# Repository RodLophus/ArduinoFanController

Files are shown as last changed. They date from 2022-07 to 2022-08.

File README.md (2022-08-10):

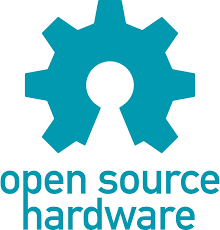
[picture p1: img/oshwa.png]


# ArduinoFanController

Controls and monitors up to 4 PC-like fans based on the readings of an NTC temperature sensor.

The device can be used in two fashions:

- As a standalone module.  In this case, it will need to be connected to a computer via USB port only to perform the initial configuration.

- "Online". The module is connected to a USB port, allowing the temperature, PWM duty cycle and fan speed to be monitored and the configuration to be changed at any time.

## Specifications

4 4-pin fan connections.  Each fan speed is monitored individually.
2 configurable PWM channels (1 channel for each 2 fans).
1 NTC temperature sensor.

Each PWM channel have two temperature thresholds (low and high) and two values for the PWM duty cycle (minimum and maximum).  The controller will set the duty cycle as follows:

- Temperature < low temperature threshold -> Minimum PWM duty cycle
- Temperature > high temperature threshold -> Maximum PWM duty cycle
- Other cases -> PWM duty cycle varies linearly according to the temperature

## Getting Started

Connect the controller to a USB port.  It should show on the computer as a serial port.

Access the controller's serial port using a terminal program (9600bps, 8-bits, no parity, 1 stop bit)

Type <ENTER> until the message bellow shows up:

```
Press "c" to change the configuration or "m" to monitor
```

Press "c" to enter the configuration menu.

Note: you must configure **all** the parameters **before using the controller** for the first time!

```
Configuration

NTC temperature sensor:

(a) Resistance at 25 C..........: 46800 Ohm
(b) B factor....................: 3950

PWM channel 1 (fans 1 and 2):
(c) Low temperature threshold...: 40 C
(d) High temperature threshold..: 55 C
(e) Minimum PWM duty cycle......: 40 %
(f) Maximum PWM duty cycle......: 100 %

PWM channel 2 (fans 3 and 4):
(g) Low temperature threshold...: 40 C
(h) High temperature threshold..: 55 C
(i) Minimum PWM duty cycle......: 40 %
(j) Maximum PWM duty cycle......: 100 %

(z) Save and exit

```

Type the letter corresponding to the parameter you want to change.  Type the new value and press <ENTER>.

Once you finish configuring the controller, type "z" to save your changes.

Be sure to exit the configuration menu when you are done as the temperature will not be monitored when the controller is in configuration mode!

## Monitoring

Press "m" on the initial screen.  The controller will show the temperature read by the NTC sensor, the PWM duty cycle for both channels (PWM1 controls fans 1 and 2, and PWM2 controls fans 3 and 4) and the speed reading (in RPM) for all fans.  Press any key to return to the initial screen.

```
Real-time monitor.  Press any key to exit.

Temp(C) PWM1(%) PWM2(%)  RPM1  RPM2  RPM3  RPM4
26.81     40      40      210     0  5475     0
26.81     40      40      210     0  5475     0
26.83     40      40      210     0  5460     0
26.83     40      40      210     0  5460     0
26.85     40      40      210     0  5475     0
26.85     40      40      210     0  5475     0
26.86     40      40      210     0  5475     0
26.86     40      40      210     0  5475     0
26.89     40      40      210     0  5475     0
26.89     40      40      210     0  5475     0
Temp(C) PWM1(%) PWM2(%)  RPM1  RPM2  RPM3  RPM4
26.92     40      40      210     0  5475     0
26.92     40      40      210     0  5475     0
26.94     40      40      210     0  5475     0
26.94     40      40      210     0  5475     0
```

## Installation Notes

For standalone usage, close the jumper P7, so the controller can get power from the power supply cable and work with no USB connection.  In this case, you may omit all the zener diodes and replace all 150Ohm resistors with wire jumpers, as those components are intended to protect the computer's USB port from (unlikely) damages caused by fan failures.

For "online" usage, remove the jumper P7.  This way, the controller will be powered via the USB port, preventing the 5V from the power supply from being fed back to the computer's USB port.

Also for "online" usage, if your PC does not has an internal type-A USB port, you can make a USB-mini to USB-internal-header cable by cutting an USB-mini cable and installing a 5-pin (or 4-pin) "DuPont" connector on the other end.  The wires on USB cables are usually color-coded:

| Wire color | Function | DuPont connector pin |
| --- | --- | --- |
| Red | +5V | 1 |
| White | Data + | 2 |
| Green | Data - | 3 |
| Black | GND | 4 |
| (shielding braid) | Chassis ground | 5 (optional) |

The cable should look like this:

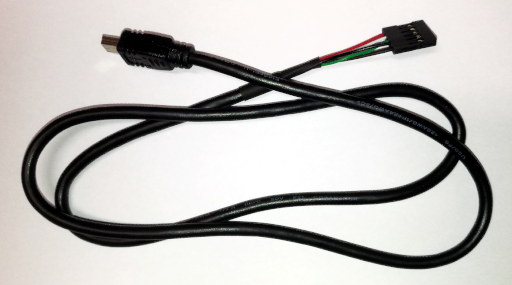
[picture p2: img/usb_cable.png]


## Bill of Materials

| Qty.  | Description | Reference Part Number | Designators |
| ----- | --- | --- | --- |
| 1 | Arduino Nano board | Arduino Nano R3 | U1 |
| 4 | 4-pin PC FAN PCB Header; Male | Molex KK254-47053 | P1, P2, P3, P4 |
| 1 | 4-pin PC accessory PCB Header; Male | Molex 8981 Series | P5 |
| 1 | 2-pin JST-XH type PCB Header; Male | JST-XH B2B-XH-A | P6 |
| 4 | Zener Diode; 5,1V; 1/2W | OnSemi 1N751A | D1, D2, D3, D4 |
| 8 | Carbon Resistor; 150 Ohm; 1/8W | (generic) | R1, R2, R3, R4, R5, R6, R10, R11 |
| 4 | Carbon Resistor; 3,9 KOhm; 1/8W | (generic) | R7, R8, R9, R12 |
| 1 | Carbon Resistor; 22 KOhm; 1/8W | (generic) | R13 |
| 4 | Polyester Capacitor; 100nf; 63V | (generic) | C1, C2, C3, C4  |

You will also need a NTC temperature sensor with a female JST-XH connector and nominal resistence between 10KOhm and 100Khm at 25˚C.  NTCs with other resistences may require R13 (and the value of REFERENCE_RESISTANCE on the source code) to be changed in order to obtain more precise temperature readings.

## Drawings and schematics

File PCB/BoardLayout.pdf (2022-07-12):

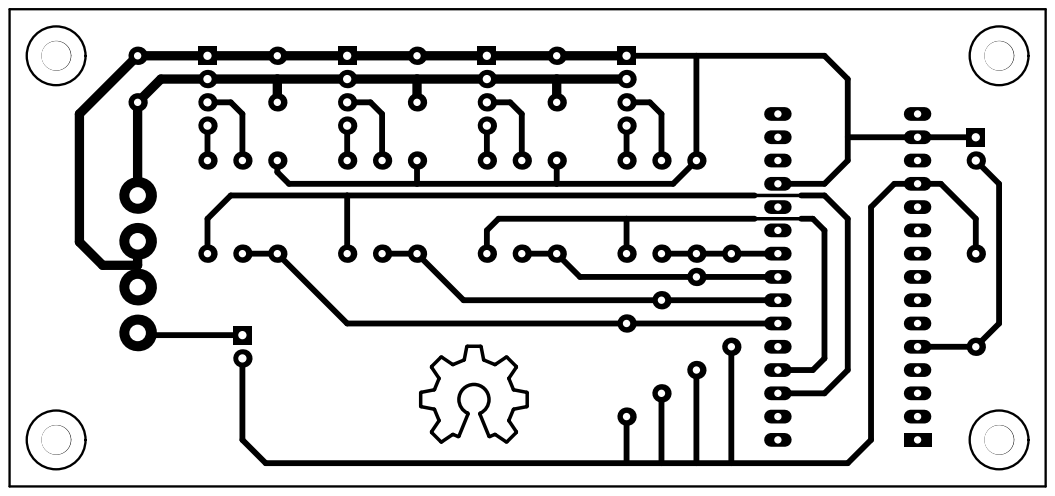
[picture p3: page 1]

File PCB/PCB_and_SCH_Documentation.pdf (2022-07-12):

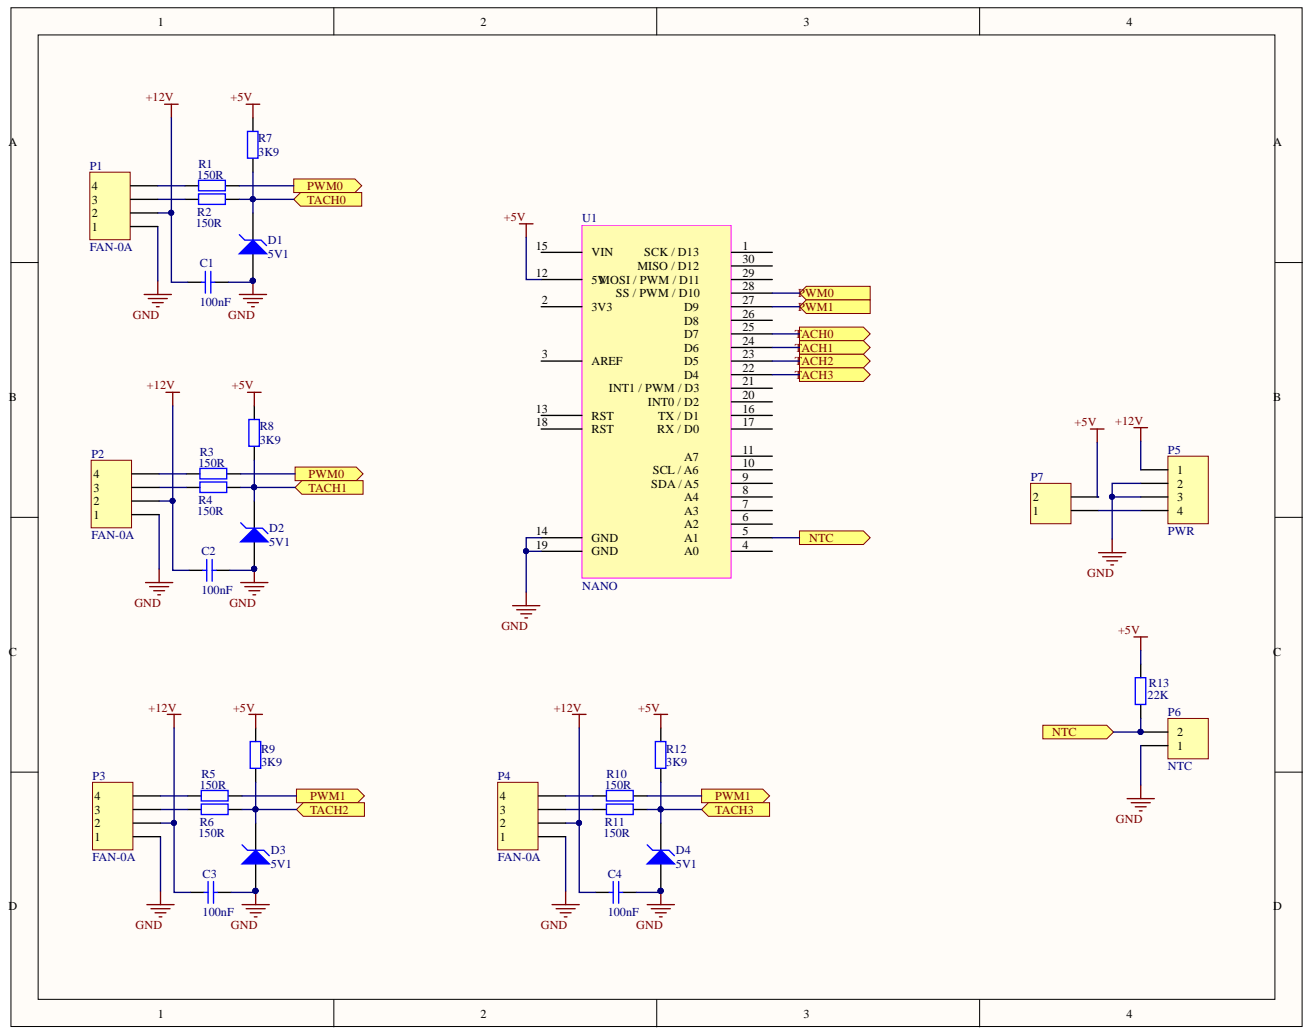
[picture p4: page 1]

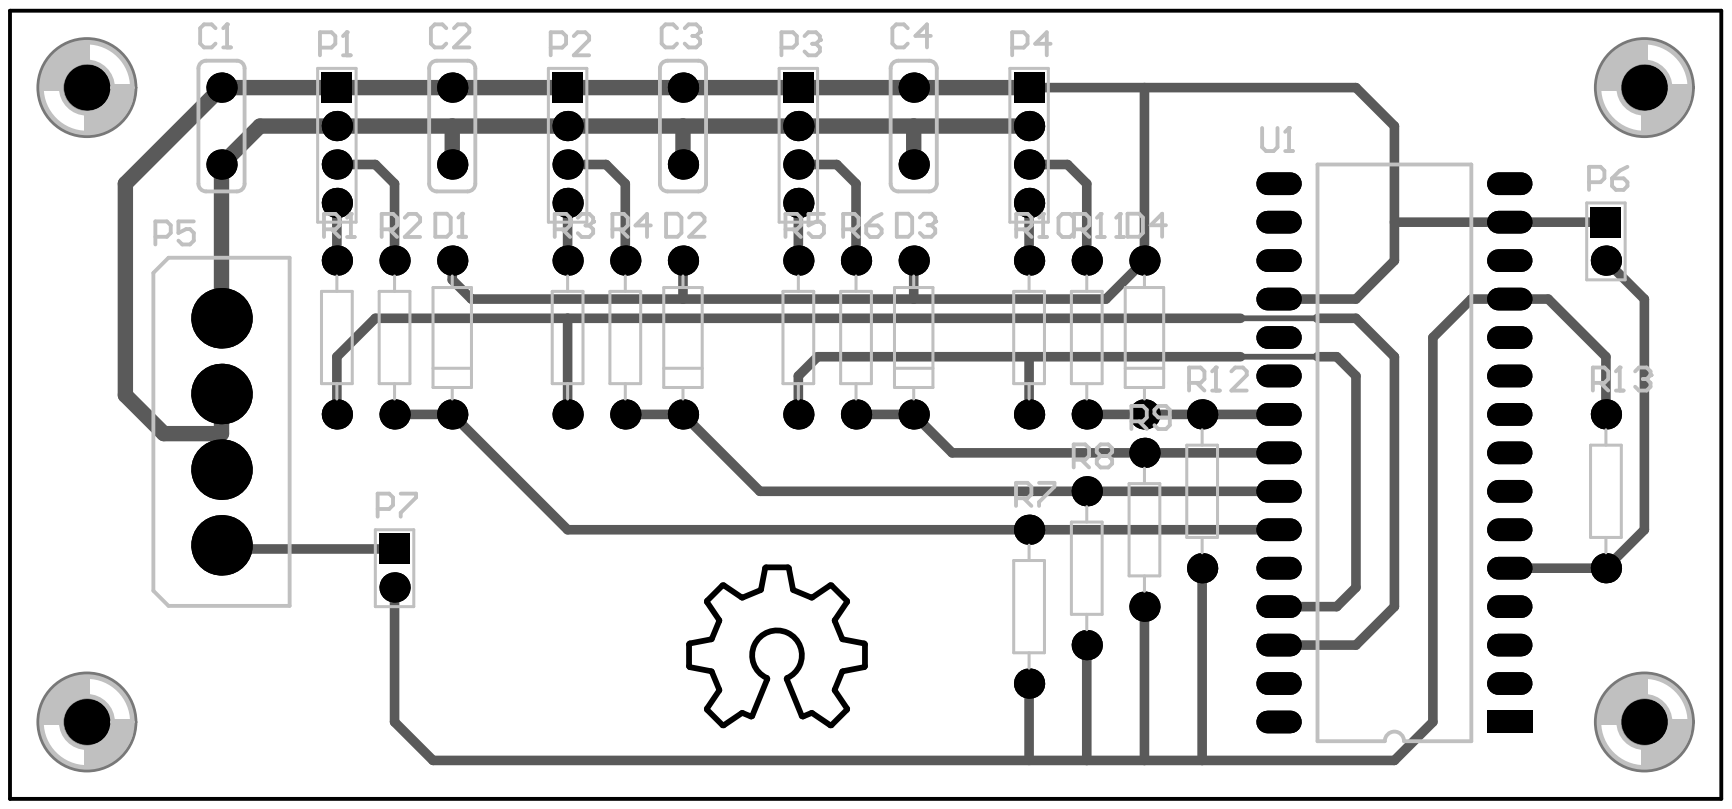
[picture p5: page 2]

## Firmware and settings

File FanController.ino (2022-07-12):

/*
 * Copyright 2022 Rodolfo B. Manin
 * This code is licensed under MIT license (see the LICENSE file for details)
 */

#include <EEPROM.h>
#include <Thermistor.h>
#include <NTC_Thermistor.h>
#include <SmoothThermistor.h>

#define WaitSerial while(Serial.available() < 1)
#define Print(a) Serial.print(a)
#define PrintLn(a) Serial.println(a)

#define NTC_PIN       A1      // Temperature sensor
#define OC1B_PIN      10      // PWM output - channel 2
#define OC1A_PIN      9       // PWM output - channel 1
#define PCINT23_PIN   7       // Fan 1 tachometer input
#define PCINT22_PIN   6       // Fan 2 tachometer input
#define PCINT21_PIN   5       // Fan 3 tachometer input
#define PCINT20_PIN   4       // Fan 4 tachometer input

// Temperature sensor parameters
#define REFERENCE_RESISTANCE  21500
#define NOMINAL_TEMPERATURE   25
#define SMOOTHING_FACTOR      5

// PWM frequency can be fine-tuned for the 16-bit Output Compare Unit (OC1) only,
// as it allows ORC1A or ICR1 to be used as the TOP limiter for TCNT1
// (for the 8-bit units, TOP = 0xFF)
#define PWM_FREQ_HZ 25000L
#define TCNT1_TOP   F_CPU / (2 * PWM_FREQ_HZ)        // formula at [Section 15.9.4]; N = 1 (no prescaling)
#define TACH_UPDATE_FREQ_HZ 1                        // how many times per second the tachometer value will be updated

struct t_ctrlChannel {
  byte lowTemp;
  byte highTemp;
  byte minPwm;
  byte maxPwm;
};

struct t_config {
  unsigned int ntcRes25;
  unsigned int ntcB;
  struct t_ctrlChannel ctrl[2];
};

struct t_config config;
Thermistor* thermistor;
byte monitorCounter = 0;
volatile byte refreshFlag = 0;
volatile word subTimer = 0;
volatile byte previousTachoInputState;
volatile word tachoCounter[] = { 0, 0, 0, 0 };
volatile word tachoRpm[] = { 0, 0, 0, 0 };


/*
 * Just print a string, a number and another string
 */
void ptnt(char *text1, int number, char *text2) {
  char buf[80];
  sprintf(buf, "%s%u%s", text1, number, text2);
  PrintLn(buf);
}


/*
 * Ask for a new value for a configuration parameter, validate the answer and save
 */
unsigned int updateConfigParam(word currentValue, word min, word max) {
  unsigned long num = 0;
  byte ch;
  while(1) {
    Print("New value (");
    Print(min); Print(" to ");  Print(max);
    Print(") ["); Print(currentValue); Print("] : ");
    while(1) {
      WaitSerial;
      ch = (byte)Serial.read();
      if((ch == 0x0D) || (ch == 0x0A)) {
        if(num == 0) {
          return currentValue;
        }
        if((num < min) || (num > max)) {
          PrintLn("  ** Out of range **");
          num = 0;
          break;
        }
        return num;
      }
      ch -= '0';
      if(ch < 11) {
        Print(ch);
        num = 10 * num + ch;
      }
    }
  }
}


/*
 * Configuration menu
 */
void updateConfig() {
  byte i;
  byte err;
  while(1) {
    PrintLn("\r\nConfiguration\n");
    PrintLn("NTC temperature sensor:");
    ptnt("(a) Resistance at 25 C..........: ", config.ntcRes25, " Ohm");
    ptnt("(b) B factor....................: ", config.ntcB, "\n");
    PrintLn("PWM channel 1 (fans 1 and 2):");
    ptnt("(c) Low temperature threshold...: ", config.ctrl[0].lowTemp, " C");
    ptnt("(d) High temperature threshold..: ", config.ctrl[0].highTemp, " C");
    ptnt("(e) Minimum PWM duty cycle......: ", config.ctrl[0].minPwm, " %");
    ptnt("(f) Maximum PWM duty cycle......: ", config.ctrl[0].maxPwm, " %\n");
    PrintLn("PWM channel 2 (fans 3 and 4):");
    ptnt("(g) Low temperature threshold...: ", config.ctrl[1].lowTemp, " C");
    ptnt("(h) High temperature threshold..: ", config.ctrl[1].highTemp, " C");
    ptnt("(i) Minimum PWM duty cycle......: ", config.ctrl[1].minPwm, " %");
    ptnt("(j) Maximum PWM duty cycle......: ", config.ctrl[1].maxPwm, " %\n");
    PrintLn("(z) Save and exit\n");
    WaitSerial;
    switch(Serial.read()) {
      case 'a': config.ntcRes25 = updateConfigParam(config.ntcRes25, 1000, 65535); break;
      case 'b': config.ntcB = (unsigned int)updateConfigParam(config.ntcB, 1000, 65535); break;
      case 'c': config.ctrl[0].lowTemp = (byte)updateConfigParam(config.ctrl[0].lowTemp, 10, 100); break;
      case 'd': config.ctrl[0].highTemp = (byte)updateConfigParam(config.ctrl[0].highTemp, 10, 100); break;
      case 'e': config.ctrl[0].minPwm = (byte)updateConfigParam(config.ctrl[0].minPwm, 0, 100); break;
      case 'f': config.ctrl[0].maxPwm = (byte)updateConfigParam(config.ctrl[0].maxPwm, 0, 100); break;
      case 'g': config.ctrl[1].lowTemp = (byte)updateConfigParam(config.ctrl[1].lowTemp, 10, 100); break;
      case 'h': config.ctrl[1].highTemp = (byte)updateConfigParam(config.ctrl[1].highTemp, 10, 100); break;
      case 'i': config.ctrl[1].minPwm = (byte)updateConfigParam(config.ctrl[1].minPwm, 0, 100); break;
      case 'j': config.ctrl[1].maxPwm = (byte)updateConfigParam(config.ctrl[1].maxPwm, 0, 100); break;
      case 'z':
        err = 0;
        for(i  = 0; i < 2; i++) {
          if(config.ctrl[i].lowTemp > config.ctrl[i].highTemp) {
            ptnt("- Low temperature threshold > high temperature threshold on channel ", i + 1, ".");
            err = 1;
          } 
          if(config.ctrl[i].minPwm > config.ctrl[i].maxPwm) {
            ptnt("- Minimum PWM duty cycle > maximum PWM duty cycle on channel ", i + 1, ".");
            err = 1;
          }
        }
        if(err) {
          PrintLn("\nConfiguration not saved. Fix the parameters above and try again.\n");
          PrintLn("Press any key...");
          WaitSerial;
          Serial.read();
        } else {
          EEPROM.put(0, config);
          PrintLn("Configuration updated.\n");
          return;
        }
    }
  }
}


/*
 * Sets the PWM duty cycle for a channel
 */
void setPwm(byte module, byte duty_cycle) {
  word n = (word) (duty_cycle * TCNT1_TOP) / 100;
  if(module == 1) OCR1A = n;
  if(module == 0) OCR1B = n;
}


/*
 * Output compare (PWM generator) initialization
 */
void pwmOutputInit() {
  pinMode(OC1A_PIN, OUTPUT);
  pinMode(OC1B_PIN, OUTPUT);
  // CS[12..10]   = 0b001 : Clock source = I/Oclk; no prescaling
  // COM1x1[1..0] = 0b10  : non-inverting compare output mode [Section 15.9.4] and [Table 15.4]
  // WGM[13..10]  = 15    : Phase correct PWM; TOP = ICR1
  TCCR1A = (1 << COM1A1) | (1 << COM1B1) | (1 << WGM11);
  TCCR1B = (1 << WGM13) | (1 << CS10);
  // Enable Timer1 interrupt on overflow
  TIMSK1 = (1 << TOIE1);
  // Set Timer1 frequency
  ICR1 = TCNT1_TOP;
}


/*
 * Tachometers inputs (with interrupt on pin change) initialization
 */
void tachometerInputInit(void) {
  // Use lower external pull-ups for better noise imunity
  pinMode(PCINT23_PIN, INPUT_PULLUP);
  pinMode(PCINT22_PIN, INPUT_PULLUP);
  pinMode(PCINT21_PIN, INPUT_PULLUP);
  pinMode(PCINT20_PIN, INPUT_PULLUP);
  PCICR |= (1 << PCIF2);        // Enables pin change interrupts on PCINT[23..16] [Section 12.2.5]
  PCMSK2 |= 0b11110000;         // Enables pin change interrupts on PCINT[23..20] [Section 12.2.6]
  previousTachoInputState = PIND & 0xF0;
}


/*
 * ISR for Timer1: calculate fan speed and triggers a refresh for the real time monitor
 */
ISR(TIMER1_OVF_vect) {
  byte i;
  if(subTimer++ > (PWM_FREQ_HZ / TACH_UPDATE_FREQ_HZ)) {
    // Runs TACH_UPDATE_FREQ_HZ times / sec.
    // Calculates fan's speeds (in RPM) and resets the tacho toggle counters
    subTimer = 0;
    for(i = 0; i < 4; i++) {
      // A standard PC fan "tachometer" pin toggles its state each 1/4 revolution
      // "N" toggles per second = (N/4)*60 RPM
      tachoRpm[i] = tachoCounter[i] * (60 / 4) * TACH_UPDATE_FREQ_HZ;
      tachoCounter[i] = 0;
    }
    refreshFlag = 1;
  }
}


/*
 * ISR for pin changes: increments the change counters used for RPM calculation
 */
ISR(PCINT2_vect) {
  byte tachoInputState;
  byte changedPins;
  tachoInputState = PIND & 0xF0;
  changedPins = tachoInputState ^ previousTachoInputState;
  // Increments the tacho signal toggle counter on fans where it changed
  if(changedPins & 0b10000000) tachoCounter[0]++;
  if(changedPins & 0b01000000) tachoCounter[1]++;
  if(changedPins & 0b00100000) tachoCounter[2]++;
  if(changedPins & 0b00010000) tachoCounter[3]++;
  previousTachoInputState = tachoInputState;
}


/*
 * Arduino setup
 */
void setup() {
  EEPROM.get(0, config);
  pwmOutputInit();
  tachometerInputInit();
  Thermistor* originThermistor = new NTC_Thermistor(NTC_PIN, REFERENCE_RESISTANCE,
    (double)config.ntcRes25, NOMINAL_TEMPERATURE, (double)config.ntcB);
  thermistor = new SmoothThermistor(originThermistor, SMOOTHING_FACTOR);
  Serial.begin(9600);
}


/*
 * Arduino main loop
 */
void loop() {
  byte lineCounter = 0;
  char monitorText[50];
  double temperature;
  byte pwm[2];
  byte channel;
  if(refreshFlag) {
    temperature = thermistor->readCelsius();
    for(channel = 0; channel < 2; channel++) {
      if(temperature < config.ctrl[channel].lowTemp) {
        pwm[channel] = config.ctrl[channel].minPwm;
      } else {
        if(temperature > config.ctrl[channel].highTemp) {
          pwm[channel] = config.ctrl[channel].maxPwm;
        } else {
          pwm[channel] = ((config.ctrl[channel].maxPwm - config.ctrl[channel].minPwm) / (config.ctrl[channel].highTemp - config.ctrl[channel].lowTemp)) * 
            (temperature - config.ctrl[channel].lowTemp) + config.ctrl[channel].minPwm;
        }
      }
      setPwm(channel, pwm[channel]);
      if(monitorCounter > 0) {
        if(++monitorCounter > 10) {
          monitorCounter = 1;
          Serial.println("Temp(C)\tPWM1(%) PWM2(%)  RPM1  RPM2  RPM3  RPM4");  
        }
        sprintf(monitorText, "\t %3d     %3d     %4d  %4d  %4d  %4d", pwm[0], pwm[1], tachoRpm[0], tachoRpm[1], tachoRpm[2], tachoRpm[3]);
        Serial.print(temperature);
        Serial.println(monitorText);
      }
    }
    refreshFlag = 0;
  }
  if(Serial.available() > 0) {
    if(monitorCounter > 0) {
      Serial.read();
      PrintLn("\nReal-time monitor terminated.\n");
      monitorCounter = 0;
    } else {
      switch(Serial.read()) {
        case 'm':
          PrintLn("\nReal-time monitor.  Press any key to exit.\n");
          monitorCounter = 10;
          break;
        case 'c':
          updateConfig();
          break;
        default:
          PrintLn("Press \"c\" to change the configuration or \"m\" to monitor");
      }
    }
  }
}
